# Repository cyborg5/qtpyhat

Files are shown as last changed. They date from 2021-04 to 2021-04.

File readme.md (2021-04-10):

# QT Py Hat Software

This is the software bundle that goes with an upcoming Adafruit Learning Guide.

It is an infrared remote control that is controlled via a webpage over your local Wi-Fi network.

Uses a Raspberry Pi Zero W, an Adafruit QT Py SAMD21, and a custom open-source board to connect them and add infrared receiver and transmitter circuitry.

When complete, the learning guide will be available at
https://learn.adafruit.com/iot-ir-remote-using-raspberry-pi-zero-w-and-qtpy-hat/

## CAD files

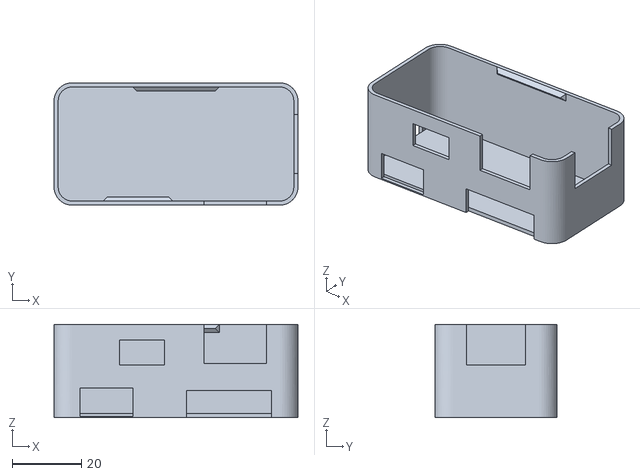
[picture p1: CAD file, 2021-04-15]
CAD_files/case.stl
70.3 x 35.2 x 26.9

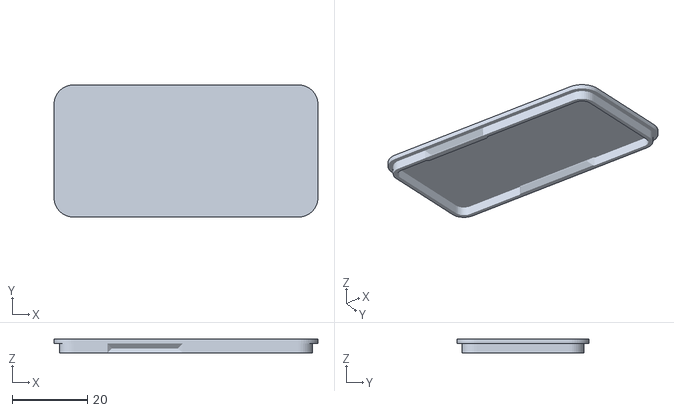
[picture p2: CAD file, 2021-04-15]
CAD_files/lid.stl
70.3 x 35.2 x 3.60

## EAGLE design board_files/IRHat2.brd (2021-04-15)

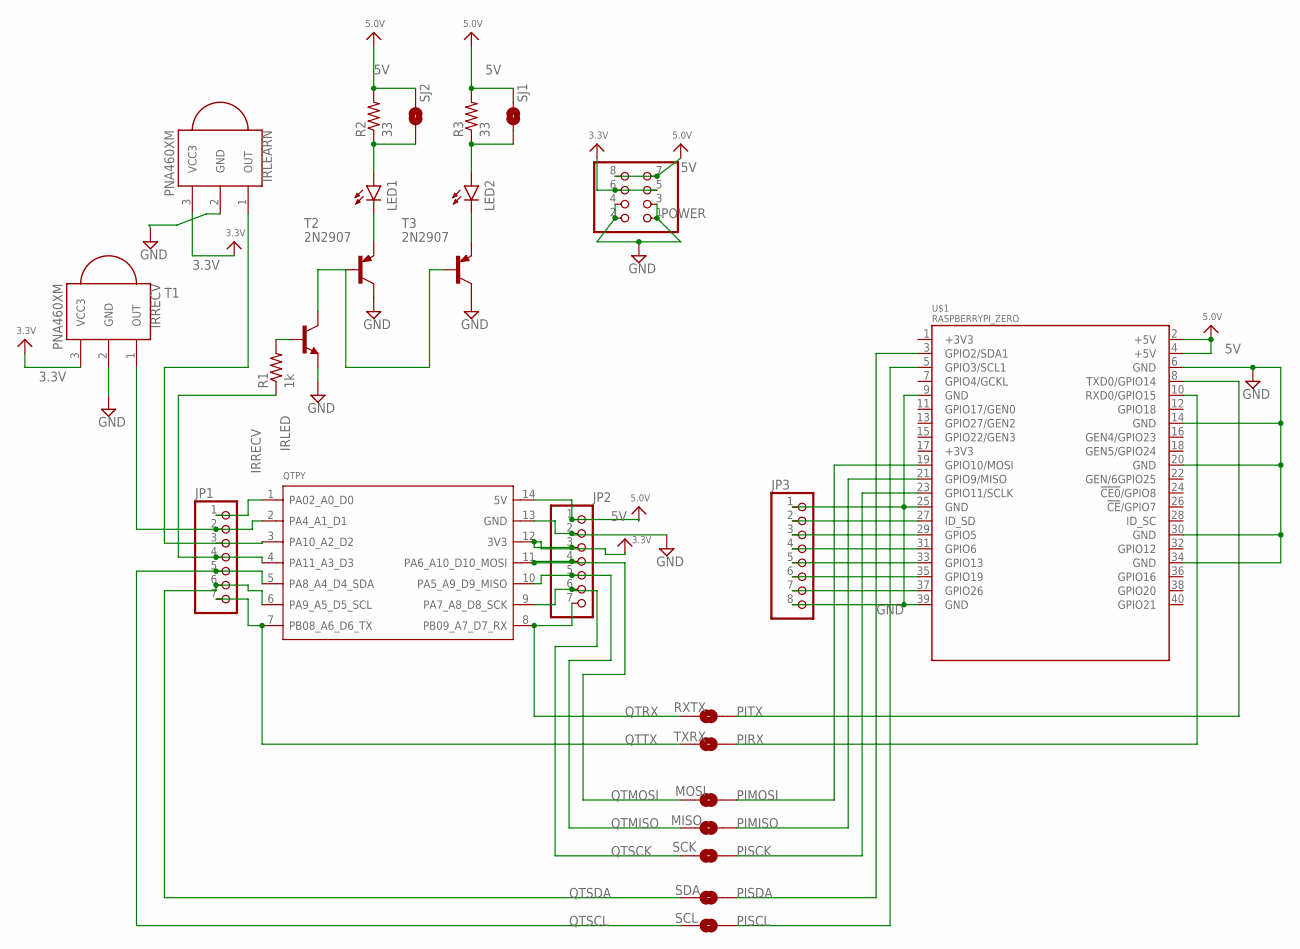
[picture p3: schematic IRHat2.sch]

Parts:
IRLEARN: PNA460XM
IRRECV: PNA460XM
JP1, JP2: PINHD-1X7; 1X07
JP3: PINHD-1X8CLEANBIG; 1X08-CLEANBIG
LED1, LED2: LED-IRTSAL6100; LED_5MM
MISO: SPARKFUN_SOLDERJUMPERNO; SPARKFUN_SJ_2S-NO
MOSI: SPARKFUN_SOLDERJUMPERNO; SPARKFUN_SJ_2S-NO
POWER: PINHD-2X4; 2X04
QTPY: MOUDLE-SEEEDUINO-XIAO; MOUDLE14P-2.54-21X17.8MM
R1: 1k; 0204/5
R2, R3: 33; 0204/5
RXTX: SPARKFUN_SOLDERJUMPERTRACE; SPARKFUN_SJ_2S-TRACE
SCK: SPARKFUN_SOLDERJUMPERNO; SPARKFUN_SJ_2S-NO
SCL: SPARKFUN_SOLDERJUMPERNO; SPARKFUN_SJ_2S-NO
SDA: SPARKFUN_SOLDERJUMPERNO; SPARKFUN_SJ_2S-NO
SJ1, SJ2: SPARKFUN_SOLDERJUMPERTRACE; SPARKFUN_SJ_2S-TRACE
T1: -NPN-TO92-EBC; TO92-EBC
T2, T3: 2N2907; TO92-CBE
TXRX: SPARKFUN_SOLDERJUMPERTRACE; SPARKFUN_SJ_2S-TRACE
U$1: RASPBERRYPI_ZERO

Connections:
3.3V: IRLEARN.3 (VCC3), IRRECV.3 (VCC3), JP2.3, POWER.5, POWER.6, QTPY.12 (3V3)
5V: JP2.1, POWER.7, POWER.8, QTPY.14 (5V), R2.2, R3.2, SJ1.2, SJ2.2, U$1.2 (+5V), U$1.4 (+5V)
GND: IRLEARN.2 (GND), IRRECV.2 (GND), JP2.2, JP3.1, JP3.8, POWER.1, POWER.2, POWER.3, POWER.4, QTPY.13 (GND), T1.E, T2.C, T3.C, U$1.6 (GND), U$1.9 (GND), U$1.14 (GND), U$1.20 (GND), U$1.25 (GND), U$1.30 (GND), U$1.34 (GND), U$1.39 (GND)
IRLED: JP1.4, QTPY.4 (PA11_A3_D3), R1.1
IRRECV: IRRECV.1 (OUT), JP1.2, QTPY.2 (PA4_A1_D1)
unnamed: JP3.2, U$1.27 (ID_SD)
unnamed: JP3.3, U$1.29 (GPIO5)
unnamed: LED1.K (C), T2.E
unnamed: R1.2, T1.B
unnamed: LED2.K (C), T3.E
unnamed: JP3.4, U$1.31 (GPIO6)
unnamed: LED2.A, R3.1, SJ1.1
unnamed: T1.C, T2.B, T3.B
unnamed: JP1.1, QTPY.1 (PA02_A0_D0)
unnamed: LED1.A, R2.1, SJ2.1
unnamed: JP3.5, U$1.33 (GPIO13)
unnamed: IRLEARN.1 (OUT), JP1.3, QTPY.3 (PA10_A2_D2)
unnamed: JP3.6, U$1.35 (GPIO19)
unnamed: JP3.7, U$1.37 (GPIO26)
PIMISO: MISO.2, U$1.21 (GPIO9/MISO)
PIMOSI: MOSI.2, U$1.19 (GPIO10/MOSI)
PIRX: TXRX.2, U$1.10 (RXD0/GPIO15)
PISCK: SCK.2, U$1.23 (GPIO11/SCLK)
PISCL: SCL.2, U$1.5 (GPIO3/SCL1)
PISDA: SDA.2, U$1.3 (GPIO2/SDA1)
PITX: RXTX.2, U$1.8 (TXD0/GPIO14)
QTMISO: JP2.5, MISO.1, QTPY.10 (PA5_A9_D9_MISO)
QTMOSI: JP2.4, MOSI.1, QTPY.11 (PA6_A10_D10_MOSI)
QTRX: JP2.7, QTPY.8 (PB09_A7_D7_RX), RXTX.1
QTSCK: JP2.6, QTPY.9 (PA7_A8_D8_SCK), SCK.1
QTSCL: JP1.5, QTPY.5 (PA8_A4_D4_SDA), SCL.1
QTSDA: JP1.6, QTPY.6 (PA9_A5_D5_SCL), SDA.1
QTTX: JP1.7, QTPY.7 (PB08_A6_D6_TX), TXRX.1

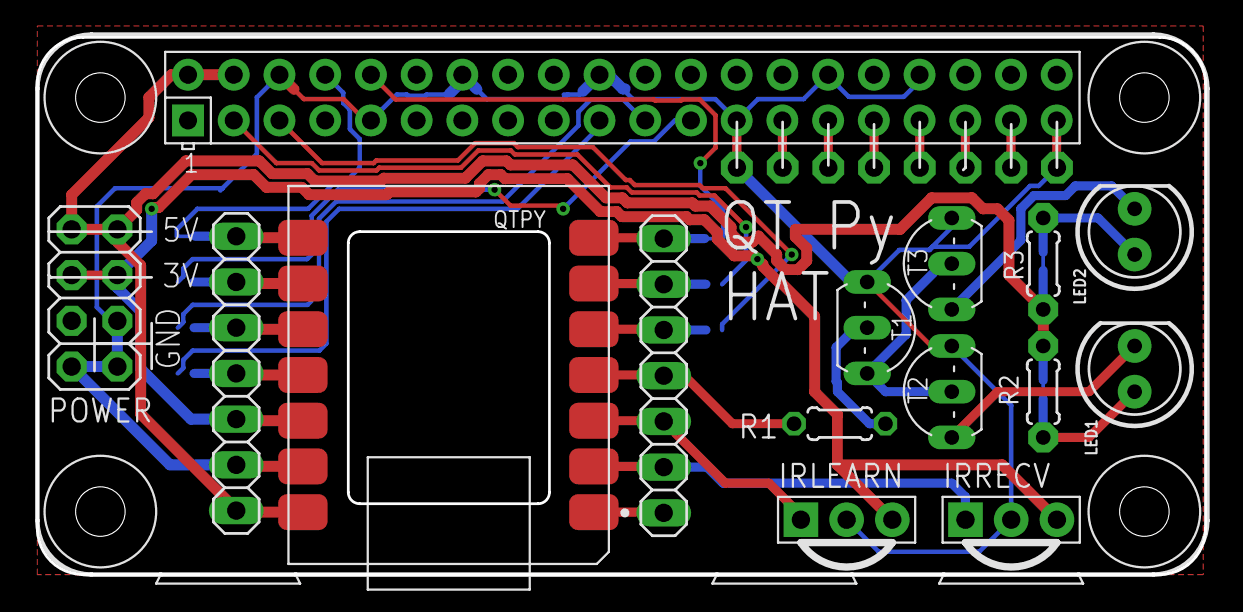
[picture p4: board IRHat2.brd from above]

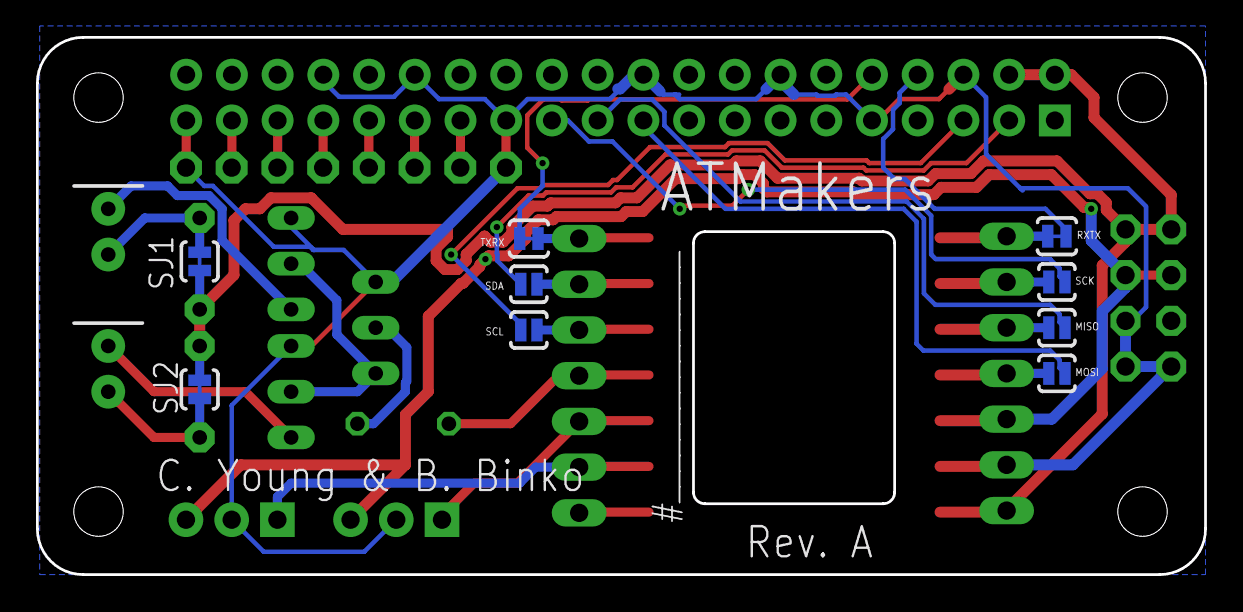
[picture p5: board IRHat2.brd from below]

Board: 2 copper layers, 64.9 x 29.8 mm, 25 parts (9 on the bottom side), 33 nets.

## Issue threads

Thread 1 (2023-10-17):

Part Not available

KevinRiTE, 2023-10-17:
The TSMP58000 is no longer available. Is the TSMP98000 a direct replacement?

cyborg5, 2023-12-18:
I'm so sorry it took me so long to get back to you on this. I took a quick look at the specs and it is recommended replacement but I didn't want to say anything until right actually tested it myself. I obtained the newer chip and verified it does work okay on a breadboard. I can't say I've soldered one into a qtpyhat yet but it should work just fine. I will update the docs on the Adafruit learning system and

Closed 2023-12-18.

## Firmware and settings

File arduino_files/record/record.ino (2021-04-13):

/* record.ino Example sketch for IRLib2
 *  Illustrate how to record a signal and then play it back.
 */
#include <IRLibDecodeBase.h>  //We need both the coding and
#include <IRLibSendBase.h>    // sending base classes
#include <IRLib_P01_NEC.h>    //Lowest numbered protocol 1st
#include <IRLib_P02_Sony.h>   // Include only protocols you want
#include <IRLib_P03_RC5.h>
#include <IRLib_P04_RC6.h>
#include <IRLib_P05_Panasonic_Old.h>
#include <IRLib_P07_NECx.h>
#include <IRLib_HashRaw.h>    //We need this for IRsendRaw
#include <IRLibCombo.h>       // After all protocols, include this
// All of the above automatically creates a universal decoder
// class called "IRdecode" and a universal sender class "IRsend"
// containing only the protocols you want.
// Now declare instances of the decoder and the sender.
IRdecode myDecoder;
IRsend mySender;

// Include a receiver either this or IRLibRecvPCI or IRLibRecvLoop
#include <IRLibRecv.h>
IRrecv myReceiver(1); //pin number for the receiver QT Py Hat

// Storage for the recorded code
uint8_t codeProtocol;  // The type of code
uint32_t codeValue;    // The data bits if type is not raw
uint8_t codeBits;      // The length of the code in bits

//These flags keep track of whether we received the first code 
//and if we have have received a new different code from a previous one.
bool gotOne, gotNew; 

void setup() {
  gotOne=false; gotNew=false;
  codeProtocol=UNKNOWN; 
  codeValue=0; 
  Serial.begin(9600);
  delay(2000);while(!Serial);//delay for Leonardo
  Serial.println(F("Send a code from your remote and we will record it."));
  Serial.println(F("Type any character and press enter. We will send the recorded code."));
  Serial.println(F("Type 'r' special repeat sequence."));
  myReceiver.enableIRIn(); // Start the receiver
}

// Stores the code for later playback
void storeCode(void) {
  gotNew=true;    gotOne=true;
  codeProtocol = myDecoder.protocolNum;
  Serial.print(F("Received "));
  Serial.print(Pnames(codeProtocol));
  if (codeProtocol==UNKNOWN) {
    Serial.println(F(" saving raw data."));
    myDecoder.dumpResults();
    codeValue = myDecoder.value;
  }
  else {
    if (myDecoder.value == REPEAT_CODE) {
      // Don't record a NEC repeat value as that's useless.
      Serial.println(F("repeat; ignoring."));
    } else {
      codeValue = myDecoder.value;
      codeBits = myDecoder.bits;
    }
    Serial.print(F(" Value:0x"));
    Serial.println(codeValue, HEX);
  }
}
void sendCode(void) {
  if( !gotNew ) {//We've already sent this so handle toggle bits
    if (codeProtocol == RC5) {
      codeValue ^= 0x0800;
    }
    else if (codeProtocol == RC6) {
      switch(codeBits) {
        case 20: codeValue ^= 0x10000; break;
        case 24: codeValue ^= 0x100000; break;
        case 28: codeValue ^= 0x1000000; break;
        case 32: codeValue ^= 0x8000; break;
      }      
    }
  }
  gotNew=false;
  if(codeProtocol== UNKNOWN) {
    //The raw time values start in decodeBuffer[1] because
    //the [0] entry is the gap between frames. The address
    //is passed to the raw send routine.
    codeValue=(uint32_t)&(recvGlobal.decodeBuffer[1]);
    //This isn't really number of bits. It's the number of entries
    //in the buffer.
    codeBits=recvGlobal.decodeLength-1;
    Serial.println(F("Sent raw"));
  }
  mySender.send(codeProtocol,codeValue,codeBits);
  if(codeProtocol==UNKNOWN) return;
  Serial.print(F("Sent "));
  Serial.print(Pnames(codeProtocol));
  Serial.print(F(" Value:0x"));
  Serial.println(codeValue, HEX);
}

void loop() {
  if (Serial.available()) {
    uint8_t C= Serial.read();
    if(C=='r')codeValue=REPEAT_CODE;
    if(gotOne) {
      sendCode();
      myReceiver.enableIRIn(); // Re-enable receiver
    }
  } 
  else if (myReceiver.getResults()) {
    myDecoder.decode();
    storeCode();
    myReceiver.enableIRIn(); // Re-enable receiver
  }
}

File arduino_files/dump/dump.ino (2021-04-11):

/* dump.ino Example sketch for IRLib2
   Illustrates how to receive an IR signal, decode it and print
   information about it to the serial monitor.
*/
//This includes everything. Not generally recommended.
//It's better to include only the parts of library you really need.
//But for this example it's quick and easy. See "comboDump" example
//for a more efficient way.
#include <IRLibAll.h>

IRrecvPCI myReceiver(1); //create receiver on pin 1 of QT Py Hat
IRdecode myDecoder;   //create decoder

void setup() {
  Serial.begin(9600);
  delay(2000); while (!Serial); //delay for Leonardo
  myReceiver.enableIRIn(); // Start the receiver
  Serial.println(F("Ready to receive IR signals"));
}

void loop() {
  //Continue looping until you get a complete signal received
  if (myReceiver.getResults()) {
    myDecoder.decode();           //Decode it
    myDecoder.dumpResults(true);  //Now print results. Use false for less detail
    myReceiver.enableIRIn();      //Restart receiver
  }
}

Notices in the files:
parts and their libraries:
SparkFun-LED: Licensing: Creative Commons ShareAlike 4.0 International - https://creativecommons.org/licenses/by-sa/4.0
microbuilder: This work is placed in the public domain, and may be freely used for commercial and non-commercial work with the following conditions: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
